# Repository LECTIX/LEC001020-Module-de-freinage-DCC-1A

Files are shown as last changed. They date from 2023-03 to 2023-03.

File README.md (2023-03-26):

# LEC001020-Module-de-freinage-DCC-1A
Fichiers sources pour le produit LEC001020

## Description du produit

Arrêtez et redémarrez vos convois de manière automatique et réaliste avec des arrêts et redémarrages progressifs des trains.
- **Technologie ABC**
- **Courrant maximum** de 1A.
- **Compatibilité DCC uniquement** (digital). Les décodeurs doivent être compatible avec la technologie ABC ([Cf. notice](docs/manual_fr.pdf)).

## Utiliser les fichiers sources pour fabriquer le produit

Il n'est **pas nécessaire de savoir souder ou d'être bon en électronique** pour se procurer ce produit. Grâce aux fichiers sources publiés ici, vous pouvez être en mesure de faire fabriquer ce produit par un sous traitant.

### Faire fabriquer chez un sous traitant

Il est aujourd'hui possible de faire fabriquer à moindre cout des cartes électroniques. Nous recommendons [JLCPCB](https://jlcpcb.com/) si vous voulez aller au moins cher. Si vous préférez un acteur européen, [eurocircuits](https://www.eurocircuits.com/) est un des acteurs reconnus.

IMAGE ALT TEXT (http://www.youtube.com/watch?v=RXGGvsUtz0c "TUTO : faire fabriquer un produit LECTIX")

1. Télécherger les sources de ce produit en cliquant sur le bouton `Code`, puis `Download ZIP`.
1. Décompresser le dossier.
1. Les fichiers pour la fabrication se trouvent dans le répertoire `hardware/prod`.
1. Se connecter sur [https://cart.jlcpcb.com/quote](https://cart.jlcpcb.com/quote)
1. Cliquer sur le bouton `Add gerber file` et sélectionner le fichier `gerbers.zip`.
1. Sélectionnez la quantité de cartes que vous souhaitez dans le champs `PCB Qty`.
1. Laisser toutes les autres options par défaut, puis cliquez sur le toggle switch en face de `PCB Assembly`, et enfin sur le bouton `confirm`.
1. Une preview de la carte électronique sans les composants doit apparaitre. Cliquez sur `NEXT`.
1. Cliquez sur le bouton `Add BOM File`, puis sélectionnez le fichier `bom.csv`
1. Cliquez sur le bouton `Add CPL File`, puis sélectionnez le fichier `pos.csv`
1. **Vérifier que tous les composants sont en stock** et bien sélectionnés, puis cliquez sur `NEXT`.
1. Une preview de la carte avec ses composants apparait. Continuer le chemin en cliquant sur `NEXT`.
1. Le prix final apparait. Sélectionnez la catégorie du produit, puis cliquez sur `SAVE TO CART`.
1. Une fois sauvegardé dans votre panier, vous pouvez valider votre commande et choisir le moyen d'acheminement. Afin de ne pas avoir à se préoccuper des frais de douane, nous vous conseillons de choisir une méthode d'expédition DDP.

Vous receverez vos cartes sous 1 à 3 semaines. 

**Nous ne sommes en aucun cas responsables des cartes qui arriveraient défectueuses ou non fonctionnelles.**

### Modifications des fichiers sources

Installez kicad 6 (ou version supérieure), et ouvrez le fichier LEC001020.kicad_pro

### Regénérer les fichiers gerber, BOM, et position (Optionnel)

Peut se faire simplement en utilisant kikit :

```
cd hardware
docker run --rm -w /kikit -v $PWD:/kikit yaqwsx/kikit kikit fab jlcpcb --assembly --no-drc --schematic LEC001020.kicad_sch --field LCSC --corrections JLCPCB_CORRECTION --nametemplate LEC001020_{} LEC001020.kicad_pcb prod/

```
## Notices
[Manuel FR](docs/manual_fr.pdf)

[Manuel EN](docs/manual_en.pdf)

## License
Tous nos fichiers sont plubliés sous la license CERN Open Hardware Licence Version 2 - Strongly Reciprocal

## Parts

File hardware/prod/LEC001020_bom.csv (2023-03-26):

Comment | Designator | Footprint | LCSC
1N4007 | D1,D2,D3,D4,D5 | Diode_SMD:D_SMA | C95872
Screw_Terminal_01x02_blue | J1 | 0_connectors:TerminalBlock_bornier-2_P5.08mm-blue | C430621
logo_lectix_25mm | LOGO1 | 0_logos:Logo_10mm

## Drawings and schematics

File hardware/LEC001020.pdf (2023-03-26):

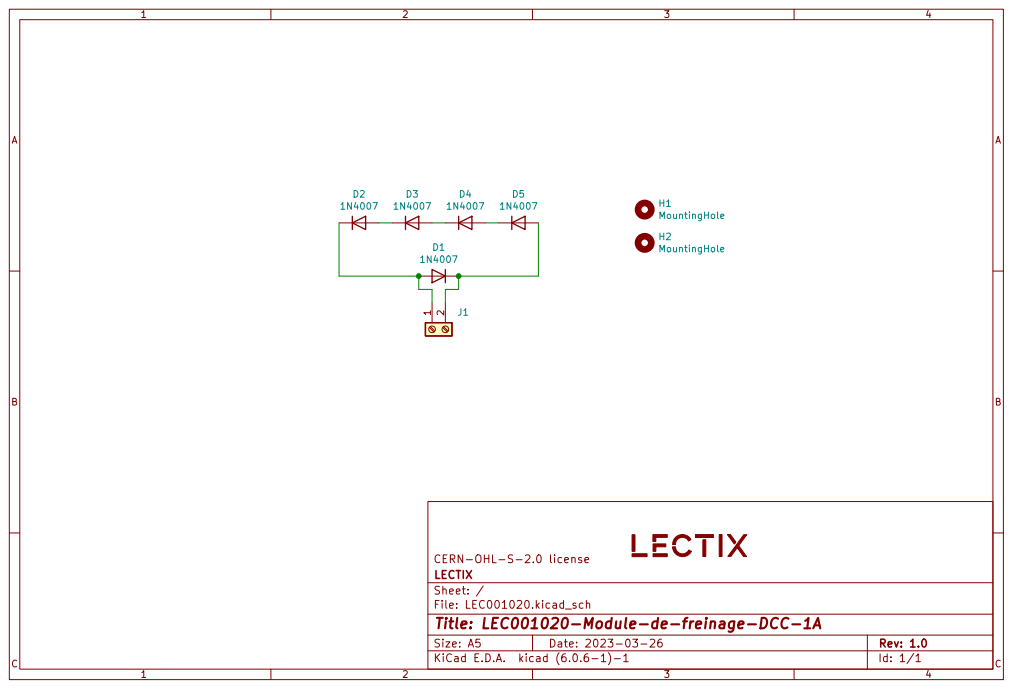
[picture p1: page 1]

File: LEC001020.kicad_sch Sheet: / LECTIX CERN-OHL-S-2.0 license

Id: 1/1 Title: LEC001020-Module-de-freinage-DCC-1A

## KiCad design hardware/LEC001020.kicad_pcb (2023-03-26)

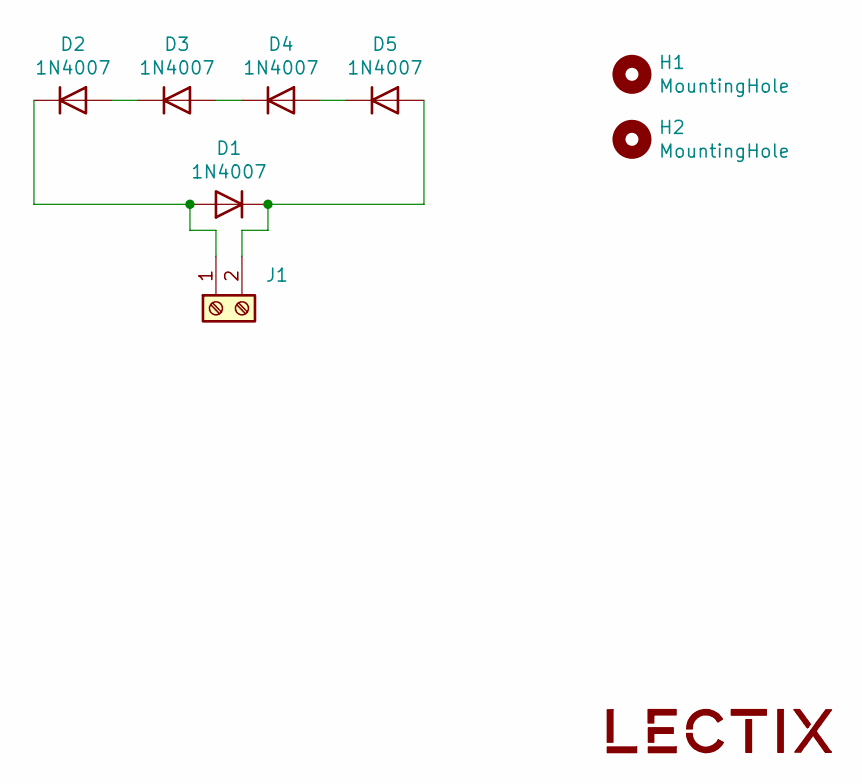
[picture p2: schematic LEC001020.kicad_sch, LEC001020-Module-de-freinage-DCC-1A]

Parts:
D1, D2, D3, D4, D5: 1N4007; D_SMA; LCSC C95872
H1, H2: MountingHole; MountingHole_3.2mm_M3
J1: Screw_Terminal_01x02_blue; TerminalBlock_bornier-2_P5.08mm-blue; MPN DB301V-5.0-2P-BU-P; LCSC C430621
LOGO1: logo_lectix_25mm; Logo_10mm

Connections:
unnamed: D1.1 (K), D5.2 (A), J1.2
unnamed: D1.2 (A), D2.1 (K), J1.1
unnamed: D2.2 (A), D3.1 (K)
unnamed: D3.2 (A), D4.1 (K)
unnamed: D4.2 (A), D5.1 (K)

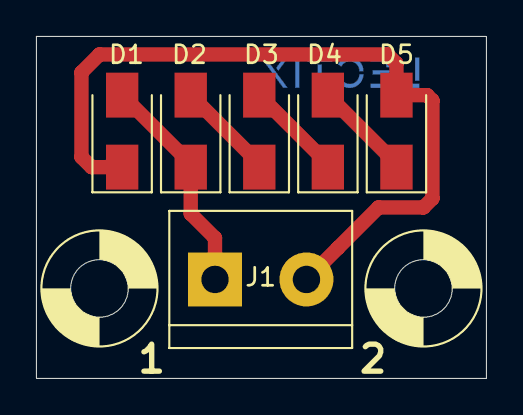
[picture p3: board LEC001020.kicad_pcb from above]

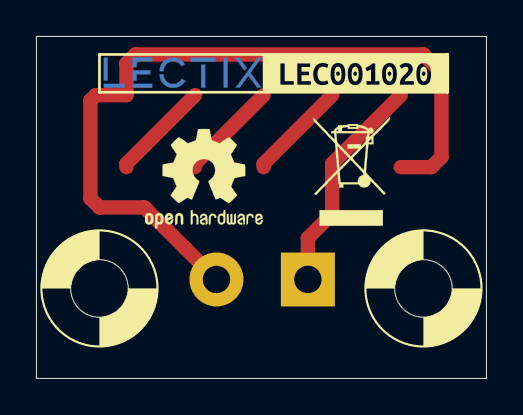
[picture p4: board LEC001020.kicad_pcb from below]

Board: 2 copper layers, 25.0 x 19.0 mm, 10 parts (2 on the bottom side), 5 nets.

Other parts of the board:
kibuzzard-62971ED3: G***; kibuzzard-62971ED3

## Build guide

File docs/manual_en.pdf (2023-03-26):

# DCC brake module

### LEC001020

## 1 Overview

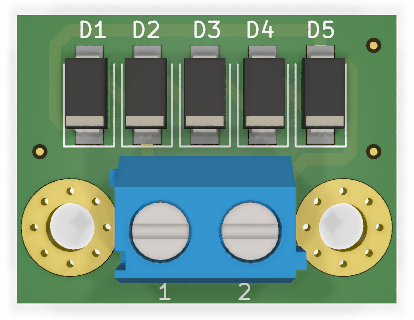
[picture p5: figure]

- Module equivalent to the BM1 module ref 22600 from Lenz.
- Allows the gradual stop and restart of trains running in a DCC environment.
- Maximum current of 1A
- ABC Breaking module for DCC only compatible with a few decoders (see section 4)
- 3 screw holes for easy mounting.

## 2 Applications

- Automatic stop of a convoy at the foot of a signal.
- Push-pull operation.
- Blocks systems - N scale.
- Automatic stop when the railway switch is not properly set.
- Automatic stop at the station.

## 3 Technical specifications

Specification | Unit | Value
Maximum continuous current | A | 1
Maximum peak current (8.3 ms) | A | 30
Dimensions | mm | 25 * 19 * 13
Weight | g | 3.1

Table 1: Specifications

LEC001020 - DCC brake module rev 1.1.0 | 1

## 4 Compatibility

☞ Warning: this module only works in digital mode and is only compatible with decoders that support ABC technology. The table 2 shows a non-exhaustive list of decoders supporting ABC technology.

This module is recommended for the N scale. For the HO scale, use the LEC001021.

Brand | Compatible decoder | Manufacturer reference
Lenz | Gold maxi GOLD+ NEM652 GOLD+ mini NEM651 GOLD+ mini wired Silver+ NEM652 Silver+ direct Silver+ 21 Silver+ Plux12 Silver+ mini NEM651 Silver+ mini wired Standard+ V2 | 10440 10433-01 10411-01 10410-01 10331-01 10330-01 10321-01 10312-01 10311-01 / 10311-02 10310-01 10231-02
ESU | LokPilot V4 / V5 LokSound V4 / V5 | All LokPilot V4 and V5 All LokSound v4 and V5

Miniature decoders

MX620, MX620N, MX620R, MX620F MX618N18,MX621, MX621N, MX621R MX621, FMX622, MX622R, MX622F, MX622N

HO decoders

MX63, MX63R, MX63F, MX63T
MX623, MX623R, MX623F, MX623P12 MX630, MX630R, MX630F, MX630P16
zimo | Thin HO decoders | MX64, MX64R, MX64F, MX64T

High power HO decoders

MX64H, MX64HR, MX64HF, MX64V MX631, MX631R, MX631F, MX631D, MX631C MX632, MX632R, MX632D, MX632C, MX632V MX632W, MX632VD, MX632WD
MX633, MX633R, MX633F, MX633P22
Miniature sound decoders | MX648, MX648R, MX648F, MX648P16
| MX646, MX646R, MX646F, MX646N, MX646L
HO sound decoders | MX645, MX645R, MX645F, MX645P16
| MX645P22, MX644D, MX644C
tOm

(trainOmatic)

LOKCOMMANDER II | All decoders of the range.

Table 2: Compatible decoders

## 5 Usage

By generating an asymmetry in the DCC signal, this module allows compatible decoders to detect areas of slowdown or shutdown and react accordingly.

There are two steps to seing up this module: installation and wiring of the module and configuration of the decoder(s).

### 5.1 Installation and wiring of the module

Note: For optimal and safe operation, the wiring of this module must be done with a wire having a minimum section of 0.2mm²

The module must be wired as shown in the figure 1. The switch is optional. It allows the module to be shunted to manually restart the stopped train.

- When the switch is open, or there is simply no switch, a signal will be emied on the right rail of the stop zone, and any machine with a compatible and configured decoder will perform a stop procedure.
- When the switch is closed, no signal will be transmied at the stop area, so no train will stop in the area. If a train was stopped in the stop area, it will restart gradually.

☞ Note : The switch can be replaced by a relay, limit switch, or any other system with at least 1A breaking capacity.

img/BM1-wiring-diagram_en.png

Figure 1: Wiring diagram for a stop zone controlled by a switch.

### 5.2 Decoder configuration

To detect the ABC signal emied by this module, the decoders must be configured accordingly. The table 3 shows the CVs used to enable or modify the decoder’s behaviour towards the ABC signal.

### 5.2.1 Determining the decoder

If you know the type of decoder in your machine, go to the next section.

To identify the brand of your decoder, you need to read the value of CV8.

Brand | Lenz | ESU | Zimo | tOm
Value of CV8 identifying the manufacturer | 99 | 151 | 145 | 78

This table is not exhaustive, you will find a more complete list on the following link: hps://www.jmri.org/xml/XSLT/pages/DecoderId.html

### 5.2.2 ABC activated

☞ In any case, you will have to activate the ABC function of the decoder so that your trains can react to the signal emied by this module.

Brand | Lenz | ESU | Zimo | tOm
ABC braking, voltage higher on the right hand side | CV51 = 2 (bit 1) | CV27 = 1 (bit 0) | CV27 = 1 (bit 0) | CV27 = 1 (bit 0)
ABC braking, voltage higher on the le hand side | - | CV27 = 2 (bit 1) | CV27 = 2 (bit 1) | CV27 = 2 (bit 1)
Activation of ABC in both directions of travel | CV51 = 6 (bits 1 + 2) | CV27 = 3 (bits 0 + 1) | CV27 = 3 (bits 0 + 1) | CV27 = 3 (bits 0 + 1)

### 5.2.3 Testing the ABC signal detection

At this point, test if the machine detects the ABC stop signal.

☞ In some configurations, the machine may not detect the ABC stop signal correctly. Some decoder brands oer additional seings to address this issue.

Brand | Lenz | ESU | Zimo | tOm
ABC Detection threshold | - | CV134 = (4 ≤ val ≤ 32) | CV134 = (101 ≤ val ≤ 114) | CV141 = (8 ≤ val ≤ 16)
Compensation for ABC signal sensing error | - | CV102 = (0 ≤ val ≤ 255) | CV142 = (0 ≤ val ≤ 255) | -

### 5.2.4 Activate constant braking distance

The constant braking distance is the seing that allows a train to stop within a certain distance, regardless of its speed. Although not mandatory, this seing is strongly recommended for optimal operation.

Brand | Lenz | ESU | Zimo | tOm
Activation of constant braking dis-tance | CV51 += 1 (bit 0) | - | CV140 = 1 | CV27 += 128 (bit 7)
Braking length | CV52 = (0 ≤ val ≤ 255) | CV254 = (1 ≤ val ≤ 255) | CV141 = (0 ≤ val ≤ 255) | CV64 = (1 ≤ val ≤ 255)

☞ The ’+=’ sign means that the value given in the table must be added to the one previously set.

### 5.2.5 CV Summary for ABC

Brand | CV | bit | Function
Lenz | 51 | 0 1 ABC activated 2 3 4 | Activation of the constant braking distance ABC direction-dependency deactivated Activate push-pull operation with intermediate stop Activate push-pull operation without intermediate stop
| 52 | - | Braking length at constant braking distance activated
ESU | 27 | 0 1 ABC braking, voltage higher on the le hand side | ABC braking, voltage higher on the right hand side
| 102 | - | Compensation for ABC signal sensing error
| 134 | - | ABC Detection threshold
| 254 | - | Constant braking distance
zimo | 27 | 0 1 ABC braking, voltage higher on the le hand side | ABC braking, voltage higher on the right hand side
| 134 | - | ABC Detection threshold
| 140 | 0 | Activation of the constant braking distance function
| 141 | - | Constant braking distance
| 142 | - | Compensation for ABC signal sensing error
tOm | 27 | 0 ABC braking, voltage higher on the right hand side 1 ABC braking, voltage higher on the le hand side 7 | Activation of the constant braking distance function
| 64 | - | Constant braking distance
| 141 | - | ABC Detection threshold

Table 3: CV for ABC

Note : if the maneuver mode or the reduced run mode is activated, the decoder will ignore the ABC signals.

## 6 Dimensions

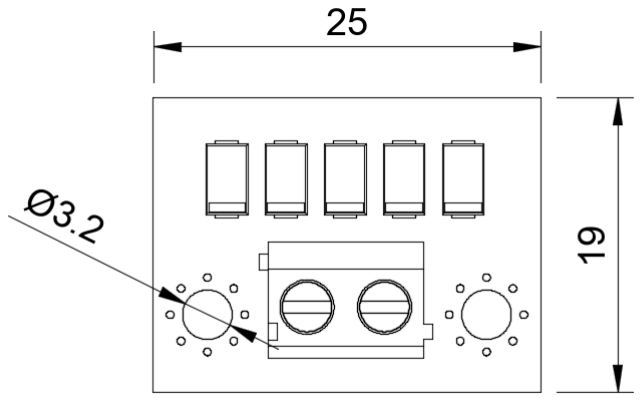
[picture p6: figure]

Figure 2: Dimensions of the module (all dimensions in mm).

## 7 Contact and support

For further information, please contact contact@lectix.fr.

## 8 Revision History

Revision | Date | Author(s) | Description
1.0.0 | 01.05.21 | TFC | Creation of the document
1.0.1 | 14.05.22 | TFC | Adding compatible decoders
1.1.0 | 30.05.22 | TFC | Added clarification in section 5.2

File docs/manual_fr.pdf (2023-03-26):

# Module de freinage DCC

### LEC001020

## 1 Caractéristiques


- Module équivalent au module BM1 ref 22600 de Lenz.
- Permet l’arrêt et le redémarrage progressif des trains en digital.
- Courrant maximum de 1A
- Module de freinage DCC utilisant la technologie ABC compatible uniquement avec certains décodeurs (Cf. section 4)
- 3 trous de fixation pour un montage facile.

## 2 Applications

- Arrêt automatique d’un convoi au pied d’un signal.
- Va et vient automatique.
- Cantons à l’échelle N.
- Arrêt automatique lorsque l’aiguillage n’est pas bien positionné.
- Arrêt automatique en gare.

## 3 Specifications technique

Specification | Unité | Valeur
Courant maximum en continu | A | 1
Courant maximum en pointe (8.3 ms) | A | 30
Dimensions | mm | 25 * 19 * 13
Poids | g | 3.1

Table 1: Spécifications

LEC001020 - Module de freinage DCC rev 1.1.0 | 1

## 4 Compatibilité

☞ Aention : ce module ne fonctionne qu’en digital et n’est compatible qu’avec les décodeurs qui supportent la technologie ABC. Le tableau 2 montre une liste non exhaustive de décodeurs supportant la technologie ABC.

Ce module est recommandé pour l’échelle N. Pour l’échelle HO, privilégiez plutôt le module LEC001021.

Marque | Décodeur compatible | Référence fabricant
Lenz | Gold maxi GOLD+ NEM652 GOLD+ mini NEM651 GOLD+ mini wired Silver+ NEM652 Silver+ direct Silver+ 21 Silver+ Plux12 Silver+ mini NEM651 Silver+ mini wired Standard+ V2 | 10440 10433-01 10411-01 10410-01 10331-01 10330-01 10321-01 10312-01 10311-01 / 10311-02 10310-01 10231-02
ESU | LokPilot V4 / V5 LokSound V4 / V5 | Tous les LokPilot V4 et V5 Tous les LokSound v4 et V5

Décodeurs miniature

MX620, MX620N, MX620R, MX620F MX618N18,MX621, MX621N, MX621R MX621, FMX622, MX622R, MX622F, MX622N

Décodeurs HO

MX63, MX63R, MX63F, MX63T
MX623, MX623R, MX623F, MX623P12 MX630, MX630R, MX630F, MX630P16
zimo | Décodeurs HO faible épaisseur | MX64, MX64R, MX64F, MX64T

Décodeurs HO forte puissance

MX64H, MX64HR, MX64HF, MX64V MX631, MX631R, MX631F, MX631D, MX631C MX632, MX632R, MX632D, MX632C, MX632V MX632W, MX632VD, MX632WD
MX633, MX633R, MX633F, MX633P22
Décodeurs sonores miniature | MX648, MX648R, MX648F, MX648P16
| MX646, MX646R, MX646F, MX646N, MX646L
Décodeurs sonores HO | MX645, MX645R, MX645F, MX645P16
| MX645P22, MX644D, MX644C
tOm

(trainOmatic)

LOKCOMMANDER II | Tous les décodeurs de la gamme.

Table 2: Décodeurs compatibles

## 5 Utilisation

En générant une asymétrie dans le signal DCC, ce module permet aux décodeurs compatibles de détecter des zones de ralentissement ou d’arrêt et de réagir en conséquence.

La mise en place de ce module se fait en deux étapes : l’installation et le câblage du module, puis la configuration du ou des décodeurs.

### 5.1 Installation et câblage du module

Remarque : pour un fonctionnement optimal et sans danger, le câblage de ce module doit se faire avec un fil possédant une section minimale de 0.2mm²

Le module doit être câblé tel que sur la figure 1. L’interrupteur est optionnel. Il permet de shunter le module pour faire repartir manuellement le train arrêté.

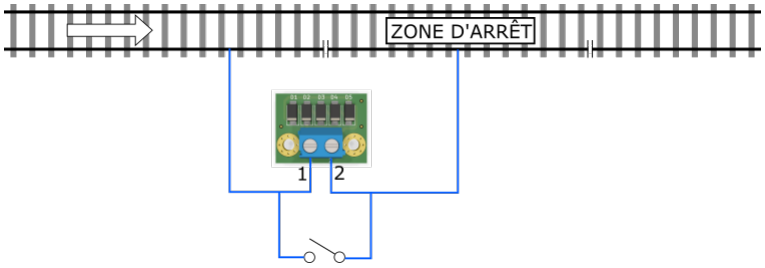
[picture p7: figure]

Figure 1: Schéma de câblage pour une zone d’arrêt contrôlée par un interrupteur.

- Lorsque l’interrupteur est ouvert, ou qu’il n’y a tout simplement pas d’interrupteur, un signal sera émis sur le rail droit de la zone d’arrêt, et toute machine équipée d’un décodeur compatible et configuré exécutera une procédure d’arrêt.
- Lorsque l’interrupteur est fermé, aucun signal ne sera transmit au niveau de la zone d’arrêt, aucun train ne s’arrêtera donc dans la zone. Si un train était arrêté dans la zone d’arrêt, il redémarrera progressivement.

☞ Note : L’interrupteur peut être remplacé par un relais, un interrupteur fin de course, ou par tout autre système ayant un pouvoir de coupure d’au moins 1A.

### 5.2 Configuration du décodeur

Pour détecter le signal ABC émis par ce module, les décodeurs doivent être configurés en conséquence. Le tableau 3 montre les CV utilisées pour activer ou modifier le comportement du décodeur vis à vis du signal ABC.

### 5.2.1 Détermination du décodeur

Si vous connaissez le type de décodeur présent dans votre machine, passez à la section suivante.

Pour identifier la marque de votre décodeur, il faut lire la valeur du CV8.

Marque | Lenz | ESU | Zimo | tOm
Valeur du CV8 identifiant le constructeur | 99 | 151 | 145 | 78

Ce tableau est non exhaustif, vous retrouverez une liste plus complète sur le lien suivant : hps://www.jmri.org/xml/XSLT/pages/DecoderId.html

### 5.2.2 Activation de l’ABC

☞ Dans tous les cas, il vous faudra activer la fonction ABC du décodeur pour que vos train puissent réagir au signal émis par ce module.

Marque | Lenz | ESU | Zimo | tOm
Activation de l’ABC dans le sens de marche classique | CV51 = 2 (bit 1) | CV27 = 1 (bit 0) | CV27 = 1 (bit 0) | CV27 = 1 (bit 0)
Activation de l’ABC dans le sens de marche inverse | - | CV27 = 2 (bit 1) | CV27 = 2 (bit 1) | CV27 = 2 (bit 1)
Activation de l’ABC dans les deux sens de marche | CV51 = 6 (bits 1 + 2) | CV27 = 3 (bits 0 + 1) | CV27 = 3 (bits 0 + 1) | CV27 = 3 (bits 0 + 1)

### 5.2.3 Tester la détection du signal ABC

A ce stade, tester si la machine détecte bien le signal d’arrêt ABC.

☞ Dans certaines configurations, la machine peut ne pas détecter correctement le signal d’arrêt ABC.
Certaines marques de décodeur proposent des paramètres de réglage supplémentaires pour répondre à ce problème.
Marque | Lenz | ESU | Zimo | tOm
Seuil de détection ABC | - | CV134 = (4 ≤ val ≤ 32) | CV134 = (101 ≤ val ≤ 114) | CV141 = (8 ≤ val ≤ 16)
Compensation erreur captage ABC | - | CV102 = (0 ≤ val ≤ 255) | CV142 = (0 ≤ val ≤ 255) | -

### 5.2.4 Activer la distance de freinage constante

La distance de freinage constante est le réglage permeant à un train de s’arrêter sur une distance déterminée, quelque soit sa vitesse. Bien que non obligatoire, ce paramètre est fortement recommandé pour un fonctionnement optimal.

Marque | Lenz | ESU | Zimo | tOm
Activation distance de freinage con-stante | CV51 += 1 (bit 0) | - | CV140 = 1 | CV27 += 128 (bit 7)
Longueur de freinage | CV52 = (0 ≤ val ≤ 255) | CV254 = (1 ≤ val ≤ 255) | CV141 = (0 ≤ val ≤ 255) | CV64 = (1 ≤ val ≤ 255)

☞ Le signe ’+=’ signifie qu’il faut additionner la valeur donnée dans le tableau avec celle configurée auparavant.

### 5.2.5 Récapitulatif CV pour l’ABC

Marque | CV | bit | Fonction
Lenz | 51 | 0 1 Activation de l’ABC 2 3 4 | Activation de la distance de freinage constante si = 1, prise en compte du signal ABC dans les deux sens de marche Activation du mode va et vient avec arrêt intermédiare Activation du mode va et vient sans arrêt intermédiaire
| 52 | - | Longueur de freinage en cas de distance de freinage constante activée
ESU | 27 | 0 1 Activation de l’ABC dans le sens de marche inverse | Activation de l’ABC dans le sens de marche classique
| 102 | - | Compensation erreur captage ABC
| 134 | - | Seuil de détection ABC
| 254 | - | Distance de freinage constante
zimo | 27 | 0 1 Activation de l’ABC dans le sens de marche inverse | Activation de l’ABC dans le sens de marche classique
| 134 | - | Seuil de détection ABC
| 140 | 0 | Activation de la fonction distance de freinage constante
| 141 | - | Distance de freinage constante
| 142 | - | Compensation erreur captage ABC
tOm | 27 | 0 Activation de l’ABC dans le sens de marche classique 1 Activation de l’ABC dans le sens de marche inverse 7 | Activation de la fonction distance de freinage constante
| 64 | - | Distance de freinage constante
| 141 | - | Seuil de détection ABC

Table 3: CV pour l’ABC

Remarque : si le mode manoeuvre ou le mode marche réduite est activé, le décodeur ne tiendra pas compte des signaux ABC.

## 6 Dimensions


Figure 2: Dimensions du module d’arrêt (toutes les côtes sont données en mm).

## 7 Contact et SAV

Pour tout renseignement, veuillez vous adresser à contact@lectix.fr.

## 8 Revision History

Revision | Date | Author(s) | Description
1.0.0 | 01.05.21 | TFC | Création du document
1.0.1 | 14.05.22 | TFC | Ajout de décodeurs compatibles
1.1.0 | 30.05.22 | TFC | Ajout de précisions dans la section 5.2

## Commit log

2023-03-26 Add source files and README
    [LEC001020.kicad_pcb, LEC001020.kicad_sch]
2023-03-26 Update schematic sheet settings + add open hardware logo
    [LEC001020.kicad_pcb, LEC001020.kicad_sch]
2023-03-26 Add prod files
    [LEC001020-CmtUser.gbr, LEC001020-CuBottom.gbl, LEC001020-CuTop.gtl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]
2023-03-26 Add pdf schematic file
